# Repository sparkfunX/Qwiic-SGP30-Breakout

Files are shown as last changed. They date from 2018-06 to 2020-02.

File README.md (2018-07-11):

Qwiic SGP30 Breakout
===========================================================
 SparkX SGP30 Breakout (Qwiic) (SPX-14813) (https://www.sparkfun.com/products/14813) 

[*SparkX SGP30 Breakout (Qwiic) (SPX-14813)*](https://www.sparkfun.com/products/14813)

The SGP30 is an indoor air quality sensor equipped with an I<sup>2</sup>C interface. It outputs equivalent CO<sub>2</sub> in ppm and Total Volatile Organic Compounds (TVOC) in ppb. The sensor also gives access to its raw measurement values of Ethanol and H<sub>2</sub>. 

The SGP30 boasts high stability with low long term drift. With its continuous baseline compensation algorithm, readings stay accurate over time. You can even fine tune your readings by interfacing with an external humidity sensor to add humidity compensation.
While the CCS811 requires a burn-in of 48 hours and a run-in of 20 minutes the SGP30 is ready to go after just 15 seconds.

This board is one of our many [Qwiic](https://www.sparkfun.com/qwiic) compatible boards! Simply plug and go. No soldering, no figuring out which is SDA or SCL, and no voltage regulation or translation required!

SparkFun labored with love to create this. Feel like supporting open source hardware? 
Buy a [board](https://www.sparkfun.com/products/14813) from SparkFun!

Repository Contents
-------------------

* **/Hardware** - Eagle design files (.brd, .sch)

Library
--------------
* **[Arduino Library](https://github.com/sparkfun/SparkFun_SGP30_Library)** - Library for SGP30

License Information
-------------------

This product is _**open source**_! 

If you have any questions or concerns on licensing, please contact techsupport@sparkfun.com.

Please use, reuse, and modify these files as you see fit. Please maintain attribution to SparkFun Electronics and release any derivative under the same license.

Distributed as-is; no warranty is given.

- Your friends at SparkFun.

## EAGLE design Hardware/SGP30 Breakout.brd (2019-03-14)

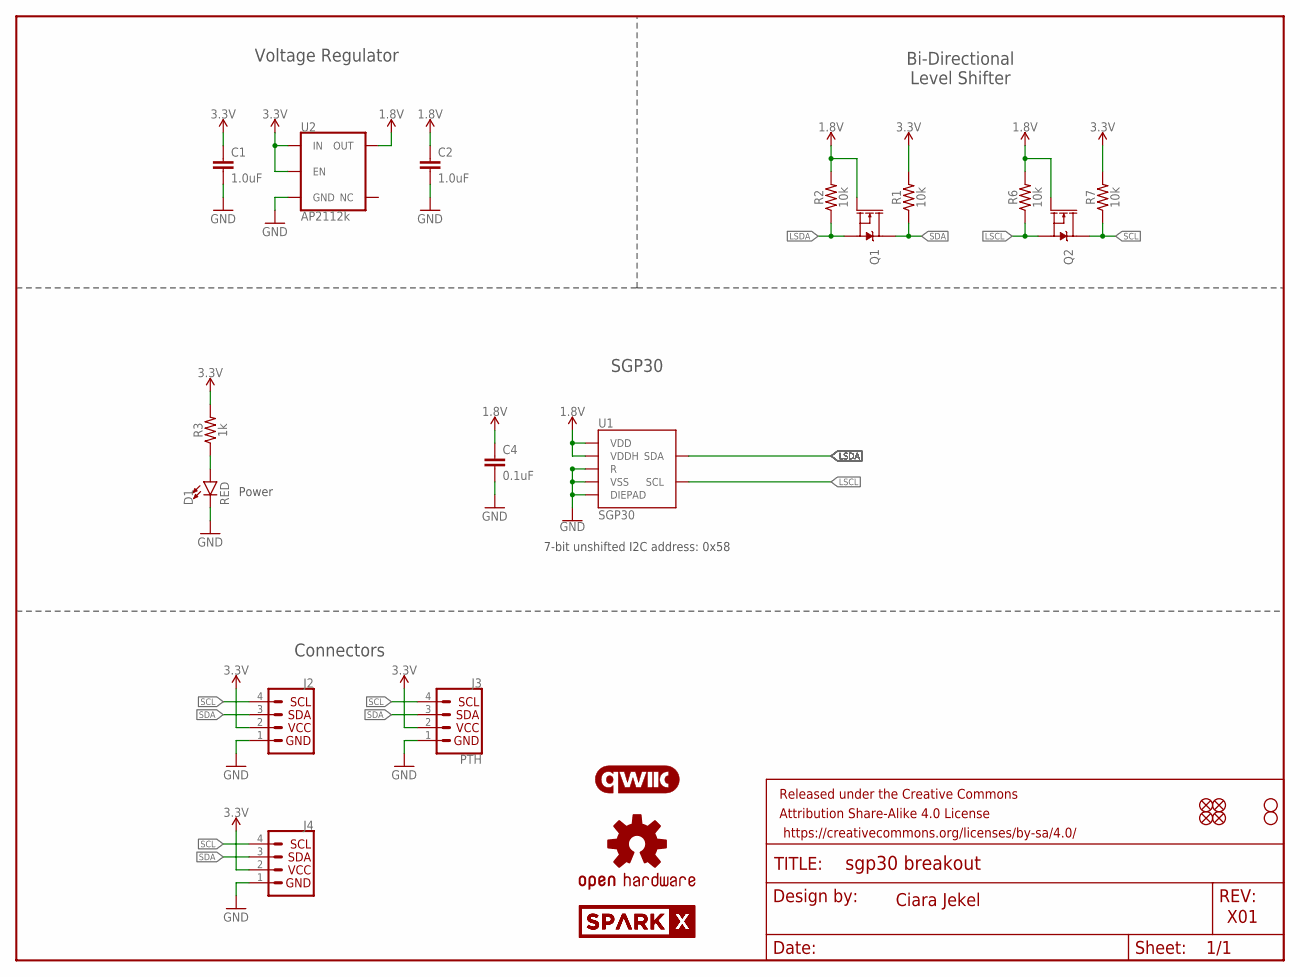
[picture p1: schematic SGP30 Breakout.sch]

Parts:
C1, C2: 1.0uF; 0603
C4: 0.1uF; 0603
D1: RED; LED-0603
FRAME1: FRAME-LETTER; CREATIVE_COMMONS
J2, J4: QWIIC_CONNECTORJS-1MM; 1X04_1MM_RA
J3: PTH; 1X04_NO_SILK
JP1, JP2, JP5, JP6: FIDUCIALUFIDUCIAL; MICRO-FIDUCIAL
JP3, JP4: STAND-OFF
LOGO1: OSHW-LOGOMINI; OSHW-LOGO-MINI
Q1, Q2: MOSFET-NCH-BSS138; SOT23-3
R1, R2, R6, R7: 10k; 0603
R3: 1k; 0603
U1: SGP30
U2: AP2112k; SOT23-5
U$1, U$2: SPARKX-LOGO4; SPARKX-MEDIUM
U$9: QWIIC_LOGO_7MM; QWIIC_7MM

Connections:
1.8V: C2.1, C4.1, Q1.1 (G), Q2.1 (G), R2.2, R6.2, U1.1 (VDD), U1.5 (VDDH), U2.5 (OUT)
3.3V: C1.1, J2.2, J3.2 (VCC), J4.2, R1.2, R3.2, R7.2, U2.1 (IN), U2.3 (EN)
GND: C1.2, C2.2, C4.2, D1.C, J2.1, J3.1 (GND), J4.1, U1.2 (VSS), U1.4 (R), U1.DIEPAD, U2.2 (GND)
LSCL: Q2.2 (S), R6.1, U1.6 (SCL)
LSDA: Q1.2 (S), R2.1, U1.3 (SDA)
unnamed: D1.A, R3.1
SCL: J2.4, J3.4 (SCL), J4.4, Q2.3 (D), R7.1
SDA: J2.3, J3.3 (SDA), J4.3, Q1.3 (D), R1.1

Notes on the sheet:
Ciara Jekel
X01
7-bit unshifted I2C address: 0x58
Power
Bi-Directional Level Shifter
Voltage Regulator
SGP30
Connectors

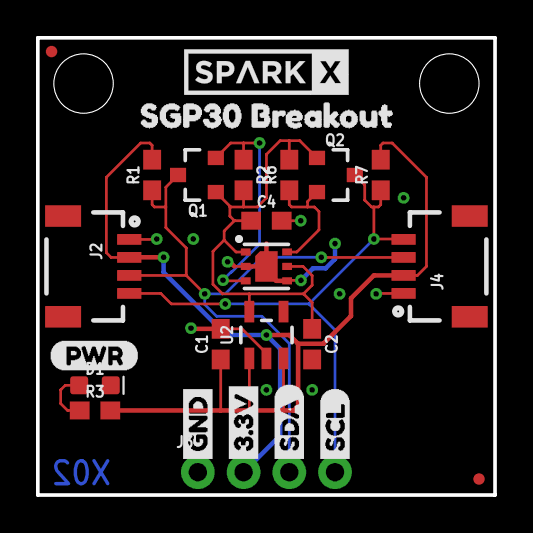
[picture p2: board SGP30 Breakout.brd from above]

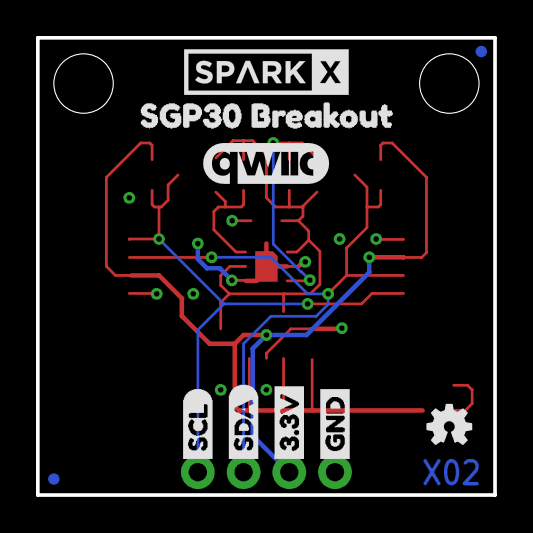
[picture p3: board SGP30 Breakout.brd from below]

Board: 2 copper layers, 25.4 x 25.4 mm, 38 parts (10 on the bottom side), 8 nets.

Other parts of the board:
U$3, U$22: GND1
U$4, U$21: 3#3V2
U$5, U$27: SDA8
U$6, U$26: SCL9
U$7, U$8: SGP30_BREAKOUT1
U$10: (PWR)

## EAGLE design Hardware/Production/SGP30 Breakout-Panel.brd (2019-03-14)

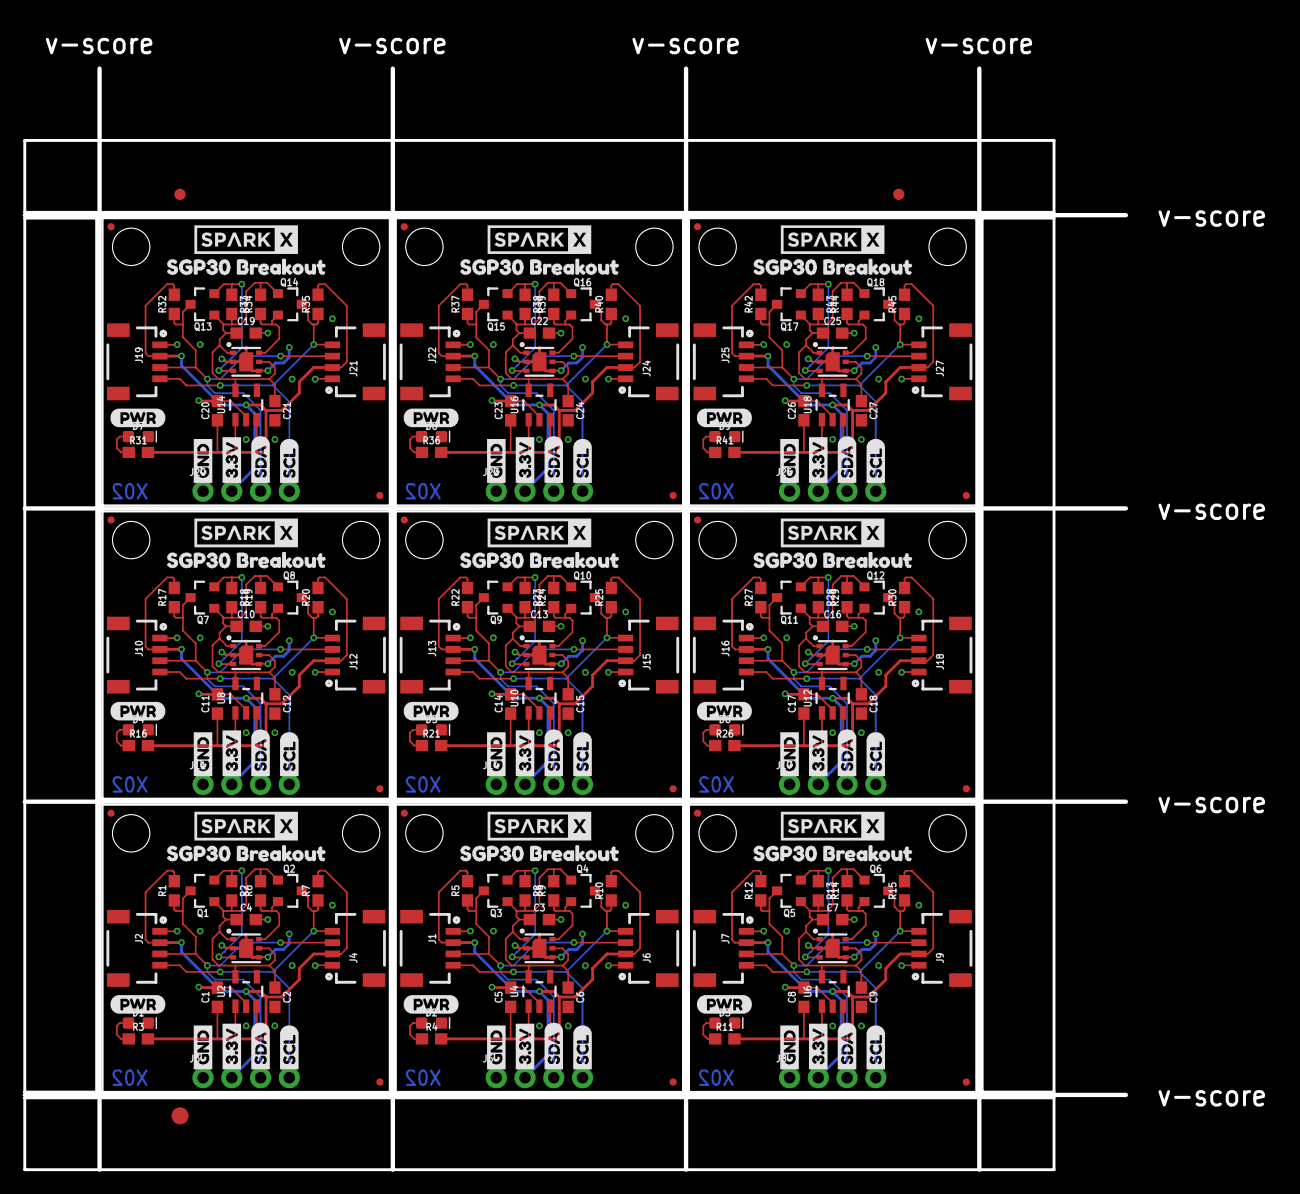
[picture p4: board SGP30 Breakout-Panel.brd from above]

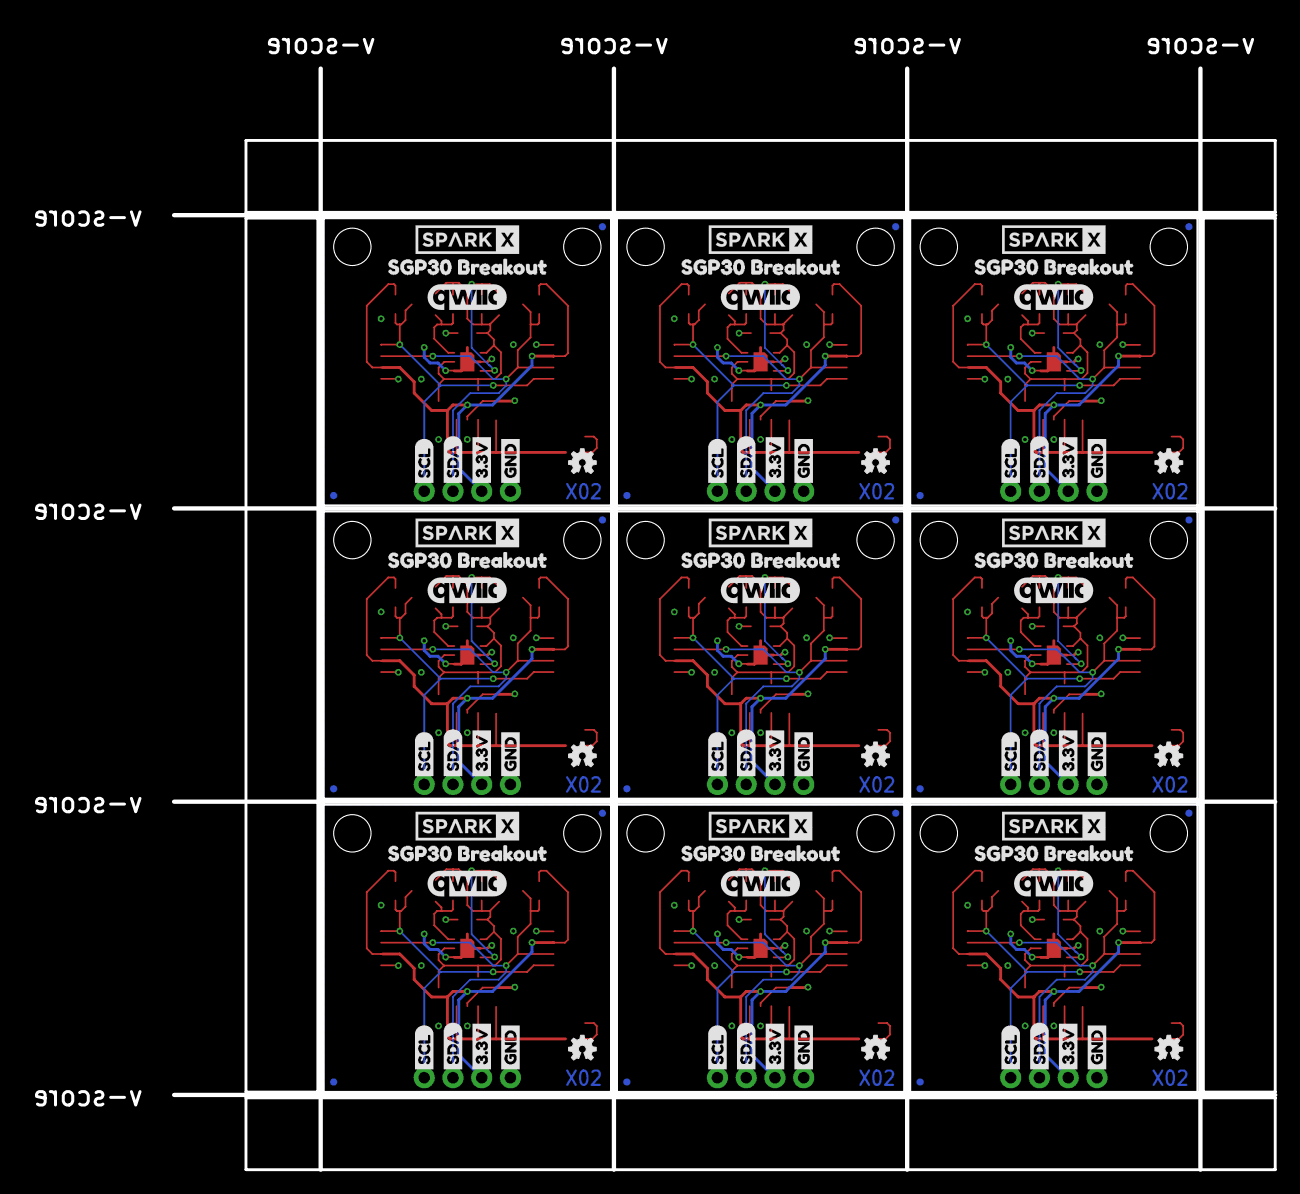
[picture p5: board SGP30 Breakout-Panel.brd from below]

Board: 2 copper layers, 97.3 x 97.3 mm, 336 parts (90 on the bottom side), 72 nets.

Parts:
C1, C2, C5, C6, C8, C9, C11, C12, C14, C15, C17, C18, C20, C21, C23, C24, C26, C27: 1.0uF; 0603
C3, C4, C7, C10, C13, C16, C19, C22, C25: 0.1uF; 0603
D1, D2, D3, D4, D5, D6, D7, D8, D9: RED; LED-0603
E$1, E$2: FIDUCIAL-1X2
E$3: FIDUCIAL-1.5X3
J1, J2, J4, J6, J7, J9, J10, J12, J13, J15, J16, J18, J19, J21, J22, J24, J25, J27: 1X04_1MM_RA
J3, J5, J8, J11, J14, J17, J20, J23, J26: PTH; 1X04_NO_SILK
JP1, JP2, JP5, JP6, JP9, JP10, JP11, JP12, JP15, JP16, JP17, JP18, JP21, JP22, JP23, JP24, JP27, JP28, JP29, JP30, JP33, JP34, JP35, JP36, JP39, JP40, JP41, JP42, JP45, JP46, JP47, JP48, JP51, JP52, JP53, JP54: FIDUCIALUFIDUCIAL; MICRO-FIDUCIAL
JP3, JP4, JP7, JP8, JP13, JP14, JP19, JP20, JP25, JP26, JP31, JP32, JP37, JP38, JP43, JP44, JP49, JP50: STAND-OFF
LOGO1, LOGO2, LOGO3, LOGO4, LOGO5, LOGO6, LOGO7, LOGO8, LOGO9: OSHW-LOGOMINI; OSHW-LOGO-MINI
Q1, Q2, Q3, Q4, Q5, Q6, Q7, Q8, Q9, Q10, Q11, Q12, Q13, Q14, Q15, Q16, Q17, Q18: SOT23-3
R1, R2, R5, R6, R7, R8, R9, R10, R12, R13, R14, R15, R17, R18, R19, R20, R22, R23, R24, R25, R27, R28, R29, R30, R32, R33, R34, R35, R37, R38, R39, R40, R42, R43, R44, R45: 10k; 0603
R3, R4, R11, R16, R21, R26, R31, R36, R41: 1k; 0603
U1, U3, U5, U7, U9, U11, U13, U15, U17: SGP30
U2, U4, U6, U8, U10, U12, U14, U16, U18: AP2112k; SOT23-5
U$1, U$2, U$11, U$12, U$29, U$30, U$43, U$44, U$57, U$58, U$71, U$72, U$85, U$86, U$99, U$100, U$113, U$114: SPARKX-LOGO4; SPARKX-MEDIUM
U$3, U$14, U$17, U$22, U$32, U$35, U$46, U$49, U$60, U$63, U$74, U$77, U$88, U$91, U$102, U$105, U$116, U$119: GND1
U$4, U$13, U$18, U$21, U$31, U$36, U$45, U$50, U$59, U$64, U$73, U$78, U$87, U$92, U$101, U$106, U$115, U$120: 3#3V2
U$5, U$16, U$19, U$27, U$34, U$37, U$48, U$51, U$62, U$65, U$76, U$79, U$90, U$93, U$104, U$107, U$118, U$121: SDA8
U$6, U$15, U$20, U$26, U$33, U$38, U$47, U$52, U$61, U$66, U$75, U$80, U$89, U$94, U$103, U$108, U$117, U$122: SCL9
U$7, U$8, U$24, U$25, U$40, U$41, U$54, U$55, U$68, U$69, U$82, U$83, U$96, U$97, U$110, U$111, U$124, U$125: SGP30_BREAKOUT1
U$9, U$28, U$42, U$56, U$70, U$84, U$98, U$112, U$126: QWIIC_LOGO_7MM; QWIIC_7MM
U$10, U$23, U$39, U$53, U$67, U$81, U$95, U$109, U$123: (PWR)

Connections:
1.8V: C2.1, C4.1, Q1.1, Q2.1, R2.2, R6.2, U1.1, U1.5, U2.5
1.8V1: C3.1, C6.1, Q3.1, Q4.1, R8.2, R9.2, U3.1, U3.5, U4.5
1.8V2: C7.1, C9.1, Q5.1, Q6.1, R13.2, R14.2, U5.1, U5.5, U6.5
1.8V3: C10.1, C12.1, Q7.1, Q8.1, R18.2, R19.2, U7.1, U7.5, U8.5
1.8V4: C13.1, C15.1, Q9.1, Q10.1, R23.2, R24.2, U9.1, U9.5, U10.5
1.8V5: C16.1, C18.1, Q11.1, Q12.1, R28.2, R29.2, U11.1, U11.5, U12.5
1.8V6: C19.1, C21.1, Q13.1, Q14.1, R33.2, R34.2, U13.1, U13.5, U14.5
1.8V7: C22.1, C24.1, Q15.1, Q16.1, R38.2, R39.2, U15.1, U15.5, U16.5
1.8V8: C25.1, C27.1, Q17.1, Q18.1, R43.2, R44.2, U17.1, U17.5, U18.5
3.3V: C1.1, J2.2, J3.2, J4.2, R1.2, R3.2, R7.2, U2.1, U2.3
3.3V1: C5.1, J1.2, J5.2, J6.2, R4.2, R5.2, R10.2, U4.1, U4.3
3.3V2: C8.1, J7.2, J8.2, J9.2, R11.2, R12.2, R15.2, U6.1, U6.3
3.3V3: C11.1, J10.2, J11.2, J12.2, R16.2, R17.2, R20.2, U8.1, U8.3
3.3V4: C14.1, J13.2, J14.2, J15.2, R21.2, R22.2, R25.2, U10.1, U10.3
3.3V5: C17.1, J16.2, J17.2, J18.2, R26.2, R27.2, R30.2, U12.1, U12.3
3.3V6: C20.1, J19.2, J20.2, J21.2, R31.2, R32.2, R35.2, U14.1, U14.3
3.3V7: C23.1, J22.2, J23.2, J24.2, R36.2, R37.2, R40.2, U16.1, U16.3
3.3V8: C26.1, J25.2, J26.2, J27.2, R41.2, R42.2, R45.2, U18.1, U18.3
GND: C1.2, C2.2, C4.2, D1.C, J2.1, J3.1, J4.1, U1.2, U1.4, U1.DIEPAD, U2.2
GND1: C3.2, C5.2, C6.2, D2.C, J1.1, J5.1, J6.1, U3.2, U3.4, U3.DIEPAD, U4.2
GND2: C7.2, C8.2, C9.2, D3.C, J7.1, J8.1, J9.1, U5.2, U5.4, U5.DIEPAD, U6.2
GND3: C10.2, C11.2, C12.2, D4.C, J10.1, J11.1, J12.1, U7.2, U7.4, U7.DIEPAD, U8.2
GND4: C13.2, C14.2, C15.2, D5.C, J13.1, J14.1, J15.1, U9.2, U9.4, U9.DIEPAD, U10.2
GND5: C16.2, C17.2, C18.2, D6.C, J16.1, J17.1, J18.1, U11.2, U11.4, U11.DIEPAD, U12.2
GND6: C19.2, C20.2, C21.2, D7.C, J19.1, J20.1, J21.1, U13.2, U13.4, U13.DIEPAD, U14.2
GND7: C22.2, C23.2, C24.2, D8.C, J22.1, J23.1, J24.1, U15.2, U15.4, U15.DIEPAD, U16.2
GND8: C25.2, C26.2, C27.2, D9.C, J25.1, J26.1, J27.1, U17.2, U17.4, U17.DIEPAD, U18.2
LSCL: Q2.2, R6.1, U1.6
LSCL1: Q4.2, R9.1, U3.6
LSCL2: Q6.2, R14.1, U5.6
LSCL3: Q8.2, R19.1, U7.6
LSCL4: Q10.2, R24.1, U9.6
LSCL5: Q12.2, R29.1, U11.6
LSCL6: Q14.2, R34.1, U13.6
LSCL7: Q16.2, R39.1, U15.6
LSCL8: Q18.2, R44.1, U17.6
LSDA: Q1.2, R2.1, U1.3
LSDA1: Q3.2, R8.1, U3.3
LSDA2: Q5.2, R13.1, U5.3
LSDA3: Q7.2, R18.1, U7.3
LSDA4: Q9.2, R23.1, U9.3
LSDA5: Q11.2, R28.1, U11.3
LSDA6: Q13.2, R33.1, U13.3
LSDA7: Q15.2, R38.1, U15.3
LSDA8: Q17.2, R43.1, U17.3
unnamed: D2.A, R4.1
unnamed: D3.A, R11.1
unnamed: D1.A, R3.1
unnamed: D4.A, R16.1
unnamed: D5.A, R21.1
unnamed: D6.A, R26.1
unnamed: D7.A, R31.1
unnamed: D8.A, R36.1
unnamed: D9.A, R41.1
SCL: J2.4, J3.4, J4.4, Q2.3, R7.1
SCL1: J1.4, J5.4, J6.4, Q4.3, R10.1
SCL2: J7.4, J8.4, J9.4, Q6.3, R15.1
SCL3: J10.4, J11.4, J12.4, Q8.3, R20.1
SCL4: J13.4, J14.4, J15.4, Q10.3, R25.1
SCL5: J16.4, J17.4, J18.4, Q12.3, R30.1
SCL6: J19.4, J20.4, J21.4, Q14.3, R35.1
SCL7: J22.4, J23.4, J24.4, Q16.3, R40.1
SCL8: J25.4, J26.4, J27.4, Q18.3, R45.1
SDA: J2.3, J3.3, J4.3, Q1.3, R1.1
SDA1: J1.3, J5.3, J6.3, Q3.3, R5.1
SDA2: J7.3, J8.3, J9.3, Q5.3, R12.1
SDA3: J10.3, J11.3, J12.3, Q7.3, R17.1
SDA4: J13.3, J14.3, J15.3, Q9.3, R22.1
SDA5: J16.3, J17.3, J18.3, Q11.3, R27.1
SDA6: J19.3, J20.3, J21.3, Q13.3, R32.1
SDA7: J22.3, J23.3, J24.3, Q15.3, R37.1
SDA8: J25.3, J26.3, J27.3, Q17.3, R42.1

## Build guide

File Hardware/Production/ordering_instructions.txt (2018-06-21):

panel size, 91x91mm
PCB thickness, 1.6mm
number of layers, 2
soldermask color, Black
silkscreen color, White
oz copper, 1oz
finish, HASL lead free
stencils, top
pcs per panel, 9

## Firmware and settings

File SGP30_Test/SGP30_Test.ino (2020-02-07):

/*
  Library for the Sensirion SGP30 Indoor Air Quality Sensor
  By: Ciara Jekel
  SparkFun Electronics
  Date: June 28th, 2018
  License: This code is public domain but you buy me a beer if you use this and we meet someday (Beerware license).

  SGP30 Datasheet: https://cdn.sparkfun.com/assets/c/0/a/2/e/Sensirion_Gas_Sensors_SGP30_Datasheet.pdf

  Feel like supporting our work? Buy a board from SparkFun!
  https://www.sparkfun.com/products/14813

  This example reads the sensors calculated CO2 and TVOC values
*/

#include "SparkFun_SGP30_Arduino_Library.h" // Click here to get the library: http://librarymanager/All#SparkFun_SGP30
#include <Wire.h>

SGP30 mySensor; //create an object of the SGP30 class

int n = 0;

const int LED = 13;

void setup() {
  Serial.begin(9600);
  Wire.begin();

  //Initializes sensor for air quality readings
  //measureAirQuality should be called in one second increments after a call to initAirQuality
  pinMode(LED, OUTPUT);
}

void loop() {
  //Initialize sensor
  if (mySensor.begin() == true) {

    if (mySensor.measureRawSignals() != 0) {
      Serial.println("Nothing detected");
      digitalWrite(LED, LOW);
    }
    else {

      Serial.print("Raw H2: ");
      Serial.print(mySensor.H2);
      Serial.print(" \tRaw Ethanol: ");
      Serial.println(mySensor.ethanol);

      if (mySensor.H2 > 10000 && mySensor.H2 < 13000 && mySensor.ethanol > 14000 && mySensor.ethanol < 17000) {
        digitalWrite(LED, HIGH);
      }
    }

  } 
  delay(100);



}

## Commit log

2018-06-22 added section labels
    [SGP30 Breakout.sch]
2018-06-28 fixed missing ground connection
    [SGP30 Breakout-Panel.brd, SGP30 Breakout.brd, SGP30 Breakout.sch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]
2018-10-30 Update Hardware/SGP30 Breakout.brd
    [SGP30 Breakout.brd]
2019-03-14 Fixed ground connections
    * Pad not grounded
    * Connected pad to solde mask
    [SGP30 Breakout-Panel.brd, SGP30 Breakout.brd, SGP30 Breakout.sch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]

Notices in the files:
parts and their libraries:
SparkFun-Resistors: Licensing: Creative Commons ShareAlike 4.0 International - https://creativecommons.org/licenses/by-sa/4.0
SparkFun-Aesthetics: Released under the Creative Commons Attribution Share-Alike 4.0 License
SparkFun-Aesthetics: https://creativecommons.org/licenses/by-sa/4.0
